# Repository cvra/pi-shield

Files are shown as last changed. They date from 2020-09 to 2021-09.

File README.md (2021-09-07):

# CVRA CAN Raspberry Pi Shield

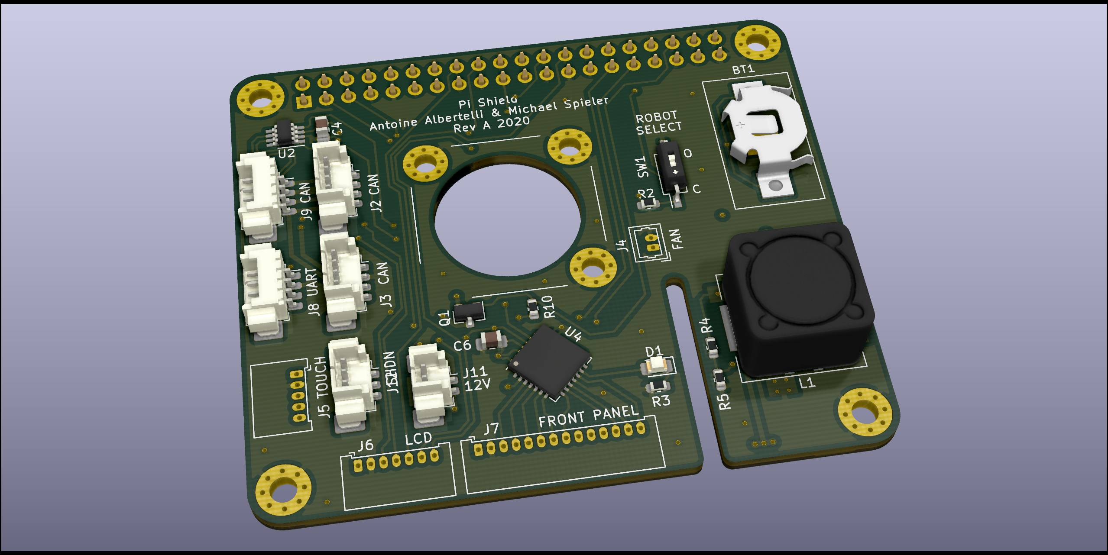
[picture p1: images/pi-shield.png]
3D view of the shield


## Features

* Power supply from 12V to 36V to 5V, 3A.
    Powers the Raspberry Pi, and optionally the CAN bus.
* MCP2515 CAN interface (compatible with Linux/SocketCAN) with transceiver and two connectors for daisy chaining.
* Connector for robot's front panel LEDs (dimmable) and pushbuttons.
* Touchscreen connector (I2C for touch, SPI for pixel data)
* DIP switch to discriminate between robots.
* Battery-backed Realtime Clock allows the robot to keep the time even when powered off.
* UART console
* Power control pins, used to cleanly shutdown the Raspberry Pi before shutting power down.
* Socket for a 20 mm DC fan.
* Slot to allow the use of the PiCam camera module.

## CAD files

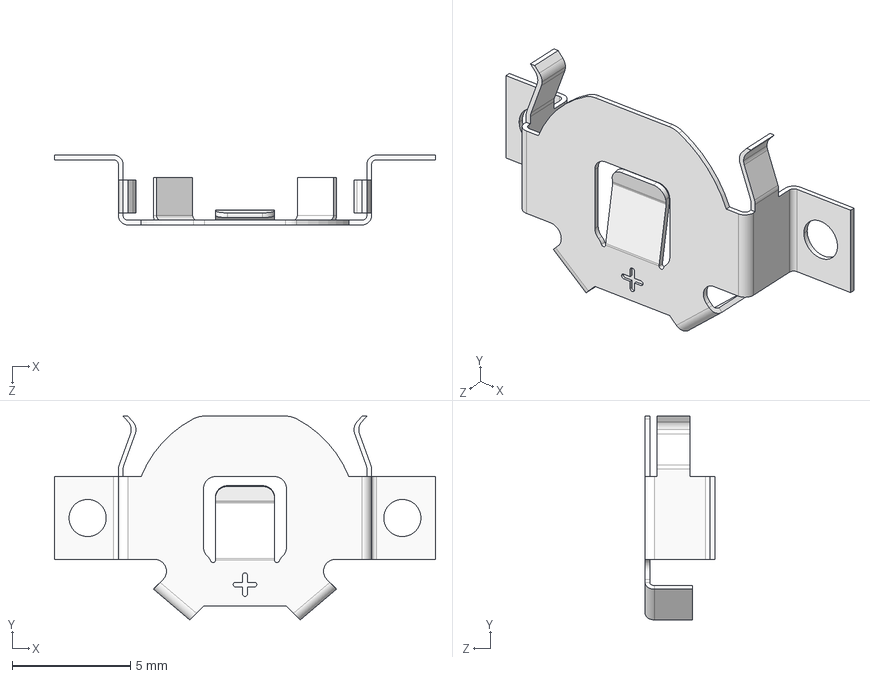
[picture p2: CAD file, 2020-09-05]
3d/BatteryHolder-3030.step
16.1 x 8.61 x 2.95 mm

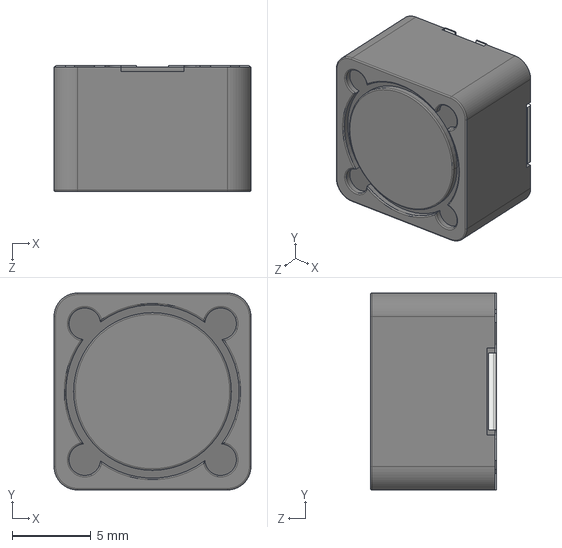
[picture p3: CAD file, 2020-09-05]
3d/DR127.step
12.5 x 12.5 x 8.00 mm

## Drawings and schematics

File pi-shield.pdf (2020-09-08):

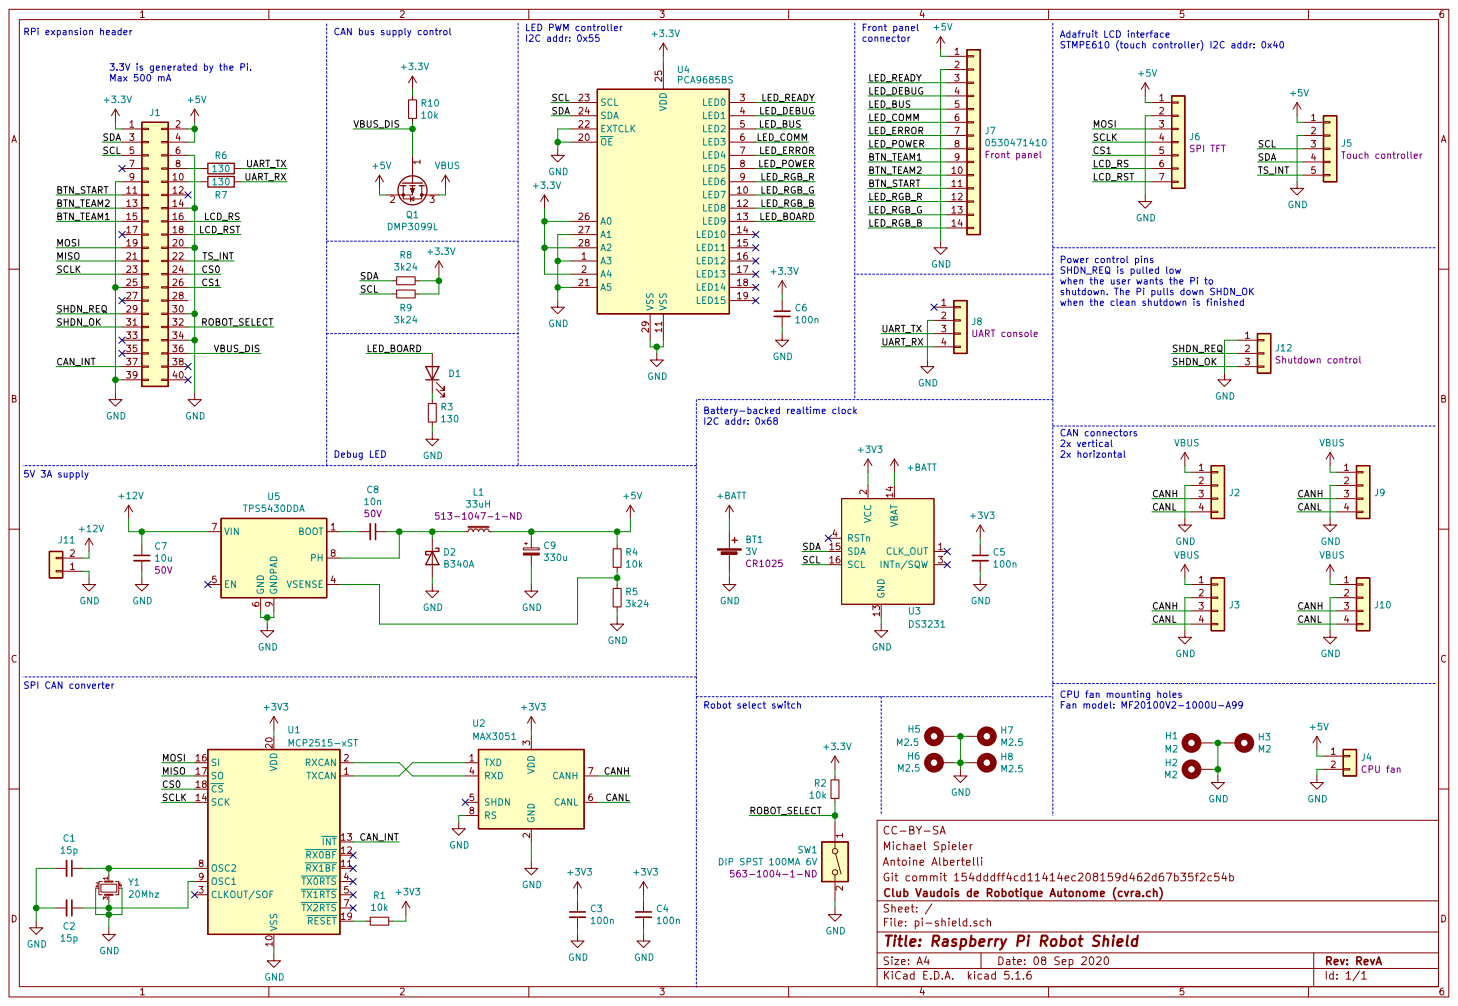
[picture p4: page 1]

Front panel connector LED PWM controller
I2C addr: 0x55

Adafruit LCD interface STMPE610 (touch controller) I2C addr: 0x40

shutdown. The Pi pulls down SHDN_OK when the clean shutdown is finished Battery-backed realtime clock

SHDN_REQ is pulled low
when the user wants the Pi to

3 RXD 4 SHDN 5 CANL 6 CANH 7 RS 8U2MAX3051

File: pi-shield.sch Sheet: / Club Vaudois de Robotique Autonome (cvra.ch) Git commit 154dddff4cd11414ec208159d462d67b35f2c54b Antoine Albertelli Michael Spieler CC-BY-SA

Id: 1/1 Title: Raspberry Pi Robot Shield

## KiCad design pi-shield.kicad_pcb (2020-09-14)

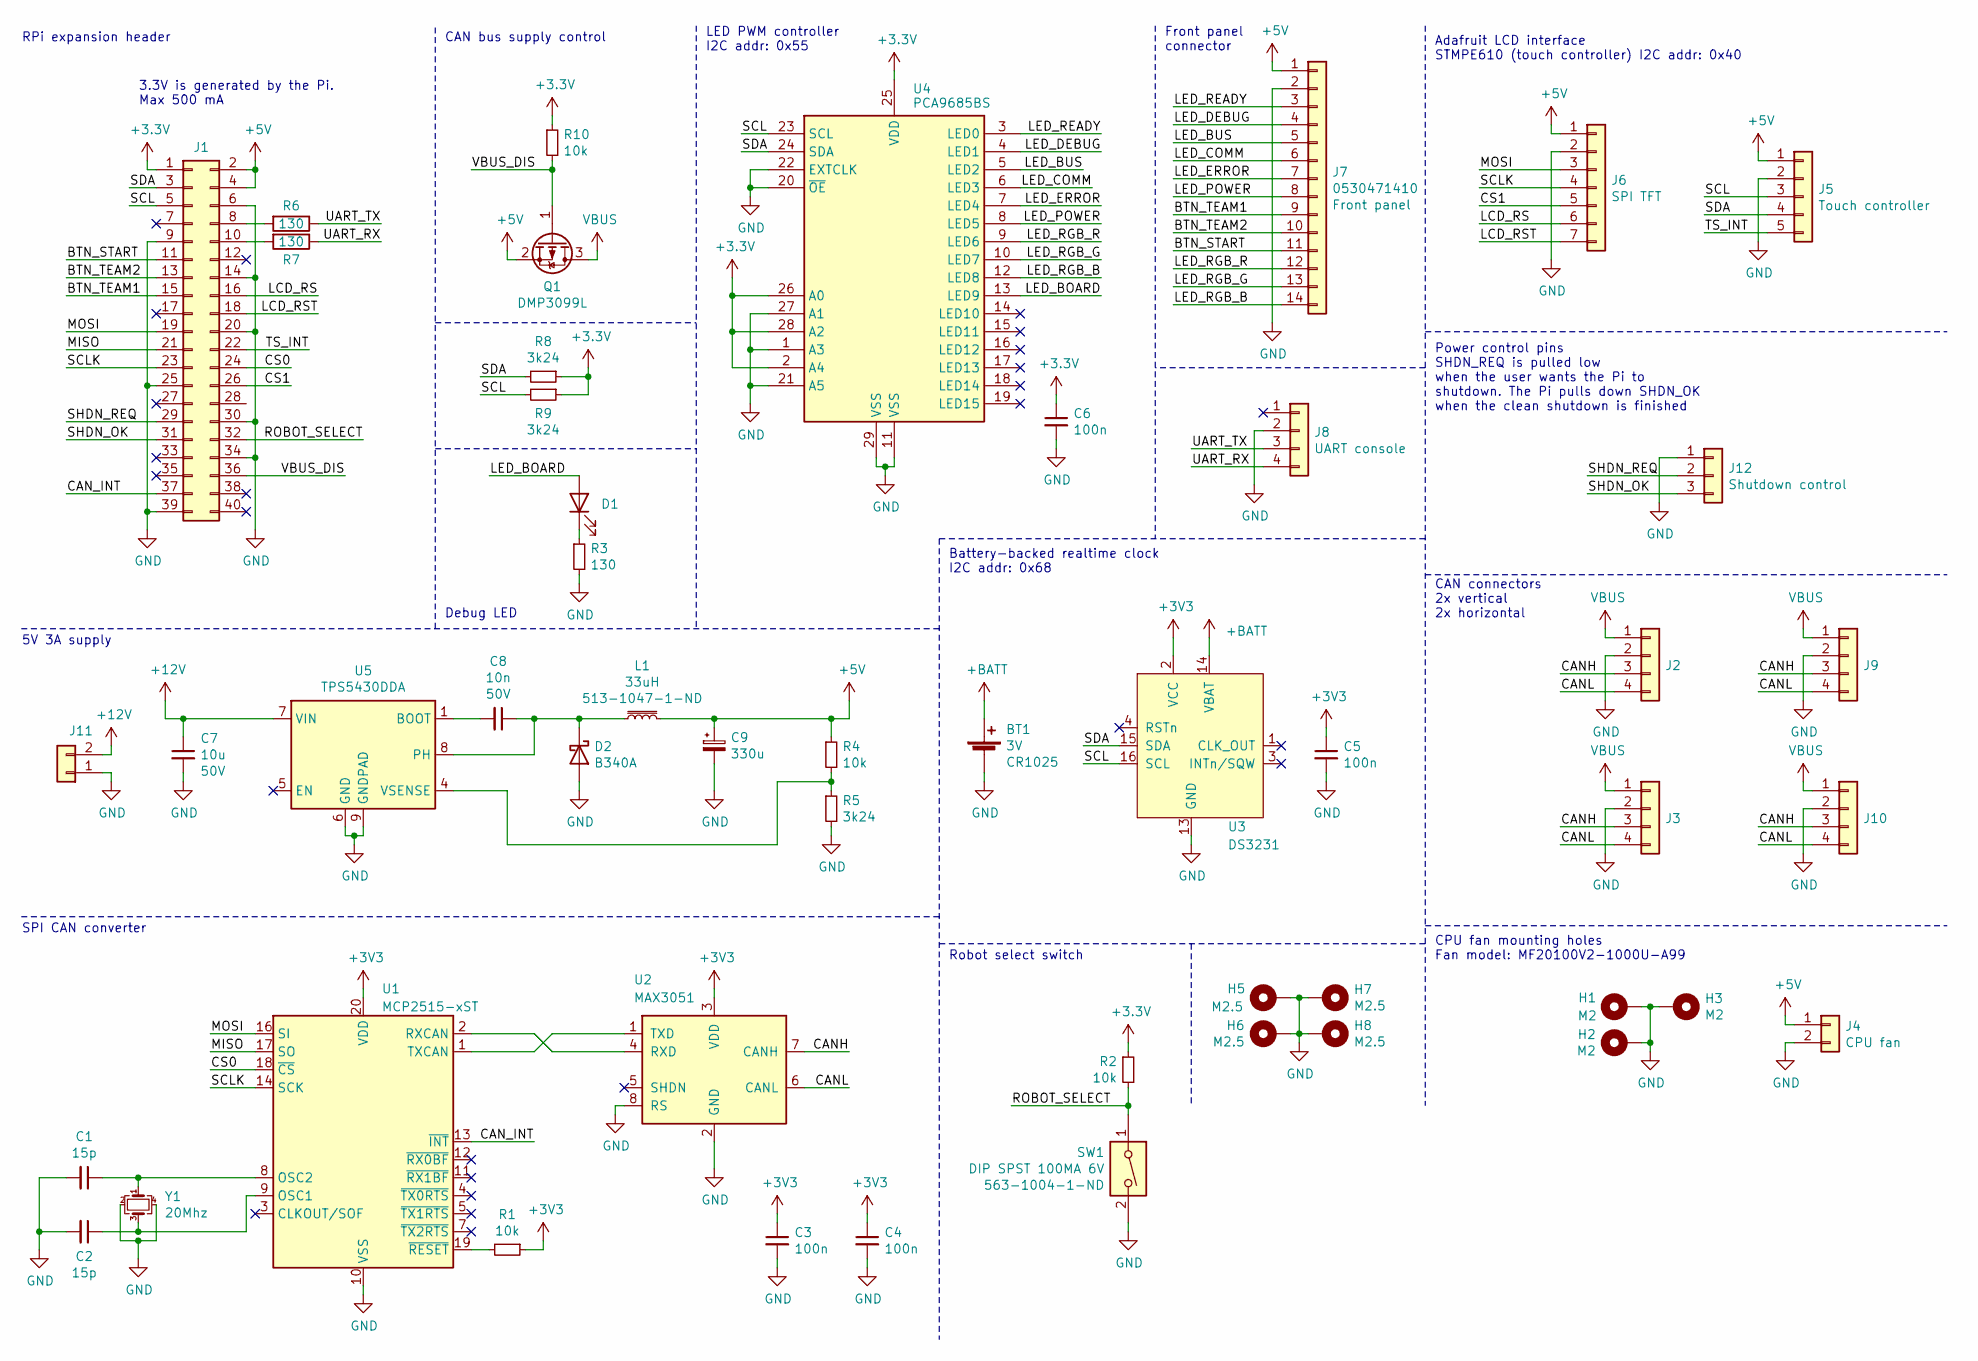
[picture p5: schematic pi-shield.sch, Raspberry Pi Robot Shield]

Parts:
BT1: 3V; 3030; digikey# 36-3030-ND
C1: 15p; C_0805_2012Metric_Pad1.15x1.40mm_HandSolder; digikey# 399-17621-1-ND
C2: 15p; C_0805_2012Metric_Pad1.15x1.40mm_HandSolder
C3: 100n; C_0805_2012Metric_Pad1.15x1.40mm_HandSolder; digikey# 399-1169-1-ND
C4, C5, C6: 100n; C_0805_2012Metric_Pad1.15x1.40mm_HandSolder
C7: 10u; C_2220_5650Metric_Pad1.97x5.40mm_HandSolder; voltage 50V; digikey# 445-3492-1-ND
C8: 10n; C_0603_1608Metric_Pad1.05x0.95mm_HandSolder; voltage 50V; digikey# 399-7842-1-ND
C9: 330u; CP_EIA-7343-30_AVX-N_Pad2.25x2.55mm_HandSolder; voltage 6.3V; digikey# 478-4114-1-ND
D1: SML-LXT0805IW-TR; LED_0805_2012Metric_Pad1.15x1.40mm_HandSolder; digikey# 67-1552-1-ND
D2: B340A; D_SMA; digikey# B340A-E3/61TGICT-ND
H1, H2, H3: M2; MountingHole_2.5mm_Pad_Via
H5, H6, H7, H8: M2.5; MountingHole_2.7mm_M2.5_Pad_Via
J1: Conn_02x20_Odd_Even; PinSocket_2x20_P2.54mm_Vertical; digikey# 1568-1462-ND
J2: Conn_01x04; Molex_PicoBlade_53398-0471_1x04-1MP_P1.25mm_Vertical; digikey# WM7608CT-ND
J3: Conn_01x04; Molex_PicoBlade_53398-0471_1x04-1MP_P1.25mm_Vertical
J4: 0530470210; Molex_PicoBlade_53047-0210_1x02_P1.25mm_Vertical; digikey# WM1731-ND
J5: Conn_01x05; Molex_PicoBlade_53048-0510_1x05_P1.25mm_Horizontal; digikey# WM1745-ND
J6: Conn_01x07; Molex_PicoBlade_53048-0710_1x07_P1.25mm_Horizontal; digikey# WM1747-ND
J7: 0530471410; Molex_PicoBlade_53048-1410_1x14_P1.25mm_Horizontal; digikey# WM17004-ND
J8: Conn_01x04; Molex_PicoBlade_53261-0471_1x04-1MP_P1.25mm_Horizontal; digikey# WM7622CT-ND
J9, J10: Conn_01x04; Molex_PicoBlade_53261-0471_1x04-1MP_P1.25mm_Horizontal
J11: 0530470210; Molex_PicoBlade_53398-0271_1x02-1MP_P1.25mm_Vertical; digikey# WM7606CT-ND
J12: Conn_01x03; Molex_PicoBlade_53398-0371_1x03-1MP_P1.25mm_Vertical; digikey# WM7607CT-ND
L1: 33uH; DR127; digikey# 513-1047-1-ND
Q1: DMP3099L; SOT-23; digikey# DMP3099L-13DICT-ND
R1, R2, R4: 10k; R_0603_1608Metric
R3: 130; R_0603_1608Metric; digikey# 311-130GRCT-ND
R5: 3k24; R_0603_1608Metric; digikey# 311-3.24KHRCT-ND
R6, R7: 130; R_0603_1608Metric
R8, R9: 3k24; R_0603_1608Metric
R10: 10k; R_0603_1608Metric; digikey# 311-10.0KHRCT-ND
SW1: DIP SPST 100MA 6V; SW_DIP_SPSTx01_Slide_Copal_CHS-01B_W7.62mm_P1.27mm; digikey# 563-1004-1-ND
U1: MCP2515-xST; TSSOP-20_4.4x6.5mm_P0.65mm; digikey# MCP2515T-I/STCT-ND
U2: MAX3051; SOT-23-8_Handsoldering; digikey# MAX3051EKA+TCT-ND
U3: DS3231; SOIC-16W_7.5x12.8mm_P1.27mm; digikey# DS3231M+TRLCT-ND
U4: PCA9685BS; QFN-28-1EP_6x6mm_P0.65mm_EP4.25x4.25mm; digikey# 568-5305-1-ND
U5: TPS5430DDA; TI_SO-PowerPAD-8_ThermalVias; digikey# 296-35990-1-ND
Y1: 20Mhz; Crystal_SMD_Abracon_ABM3C-4Pin_5.0x3.2mm; digikey# 535-11292-1-ND

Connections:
+5V: C9.1, J1.2, J1.4, J4.1, J5.1, J6.1, J7.1, L1.2, Q1.2 (S), R4.1
+12V: C7.1, J11.2, U5.7 (VIN)
+BATT: BT1.1 (+), U3.14 (VBAT)
/BTN_START: J1.11, J7.11
/BTN_TEAM1: J1.15, J7.9
/BTN_TEAM2: J1.13, J7.10
/CANH: J2.3, J3.3, J9.3, J10.3, U2.7 (CANH)
/CANL: J2.4, J3.4, J9.4, J10.4, U2.6 (CANL)
/CAN_INT: J1.37, U1.13 (~INT)
/CS0: J1.24, U1.18 (~CS)
/CS1: J1.26, J6.5
/LCD_RS: J1.16, J6.6
/LCD_RST: J1.18, J6.7
/LED_BOARD: D1.2 (A), U4.13 (LED9)
/LED_BUS: J7.5, U4.5 (LED2)
/LED_COMM: J7.6, U4.6 (LED3)
/LED_DEBUG: J7.4, U4.4 (LED1)
/LED_ERROR: J7.7, U4.7 (LED4)
/LED_POWER: J7.8, U4.8 (LED5)
/LED_READY: J7.3, U4.3 (LED0)
/LED_RGB_B: J7.14, U4.12 (LED8)
/LED_RGB_G: J7.13, U4.10 (LED7)
/LED_RGB_R: J7.12, U4.9 (LED6)
/MISO: J1.21, U1.17 (SO)
/MOSI: J1.19, J6.3, U1.16 (SI)
/ROBOT_SELECT: J1.32, R2.2, SW1.1
/SCL: J1.5, J5.3, R9.2, U3.16 (SCL), U4.23 (SCL)
/SCLK: J1.23, J6.4, U1.14 (SCK)
/SDA: J1.3, J5.4, R8.2, U3.15 (SDA), U4.24 (SDA)
/SHDN_OK: J1.31, J12.3
/SHDN_REQ: J1.29, J12.2
/TS_INT: J1.22, J5.5
/UART_RX: J8.4, R7.1
/UART_TX: J8.3, R6.1
/VBUS_DIS: J1.36, Q1.1 (G), R10.2
GND: BT1.2 (-), C1.2, C2.2, C3.2, C4.2, C5.2, C6.2, C7.2, C9.2, D2.2 (A), H1.1, H2.1, H3.1, H5.1, H6.1, H7.1, H8.1, J1.6, J1.9, J1.14, J1.20, J1.25, J1.30, J1.34, J1.39, J2.2, J3.2, J4.2, J5.2, J6.2, J7.2, J8.2, J9.2, J10.2, J11.1, J12.1, R3.2, R5.2, SW1.2, U1.10 (VSS), U2.2 (GND), U2.8 (RS), U3.13 (GND), U4.1 (A3), U4.11 (VSS), U4.20 (~OE), U4.21 (A5), U4.22 (EXTCLK), U4.27 (A1), U4.29 (VSS), U5.6 (GND), U5.9 (GNDPAD), Y1.2, Y1.4
unnamed: C1.1, U1.8 (OSC2), Y1.1
unnamed: C2.1, U1.9 (OSC1), Y1.3
unnamed: C8.1, D2.1 (K), L1.1, U5.8 (PH)
unnamed: C8.2, U5.1 (BOOT)
unnamed: D1.1 (K), R3.1
unnamed: J1.8, R6.2
unnamed: J1.10, R7.2
unnamed: R1.2, U1.19 (~RESET)
unnamed: R4.2, R5.1, U5.4 (VSENSE)
unnamed: U1.1 (TXCAN), U2.1 (TXD)
unnamed: U1.2 (RXCAN), U2.4 (RXD)
VBUS: J2.1, J3.1, J9.1, J10.1, Q1.3 (D)

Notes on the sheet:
CPU fan mounting holes Fan model: MF20100V2-1000U-A99
3.3V is generated by the Pi. Max 500 mA
Power control pins SHDN_REQ is pulled low when the user wants the Pi to shutdown. The Pi pulls down SHDN_OK when the clean shutdown is finished
SPI CAN converter
5V 3A supply
RPi expansion header
CAN bus supply control
Debug LED
LED PWM controller I2C addr: 0x55
Robot select switch
Battery-backed realtime clock I2C addr: 0x68
CAN connectors 2x vertical 2x horizontal
Adafruit LCD interface STMPE610 (touch controller) I2C addr: 0x40
Front panel connector

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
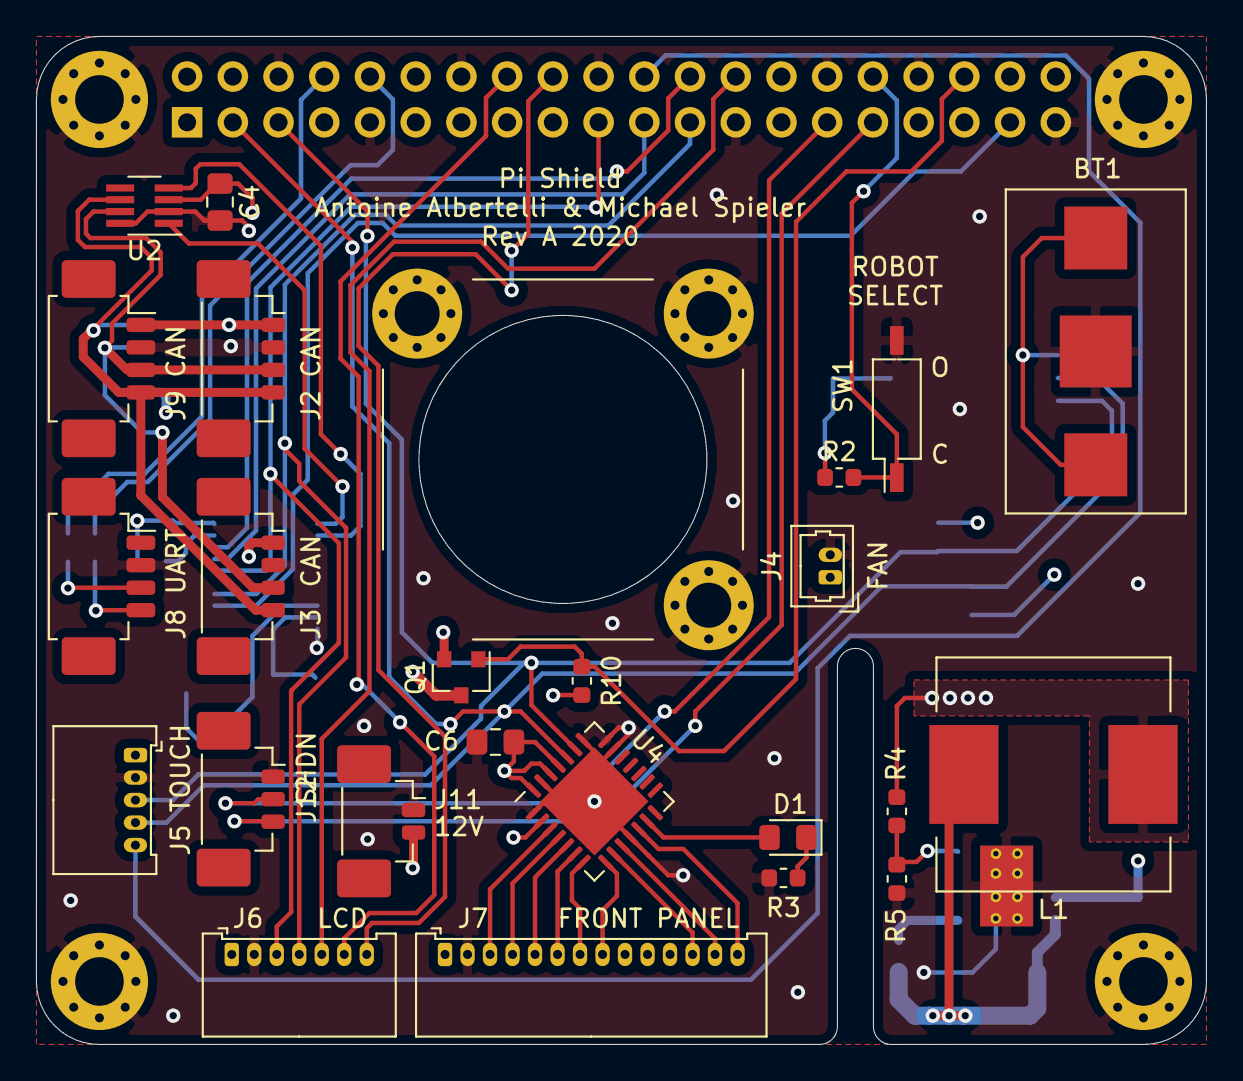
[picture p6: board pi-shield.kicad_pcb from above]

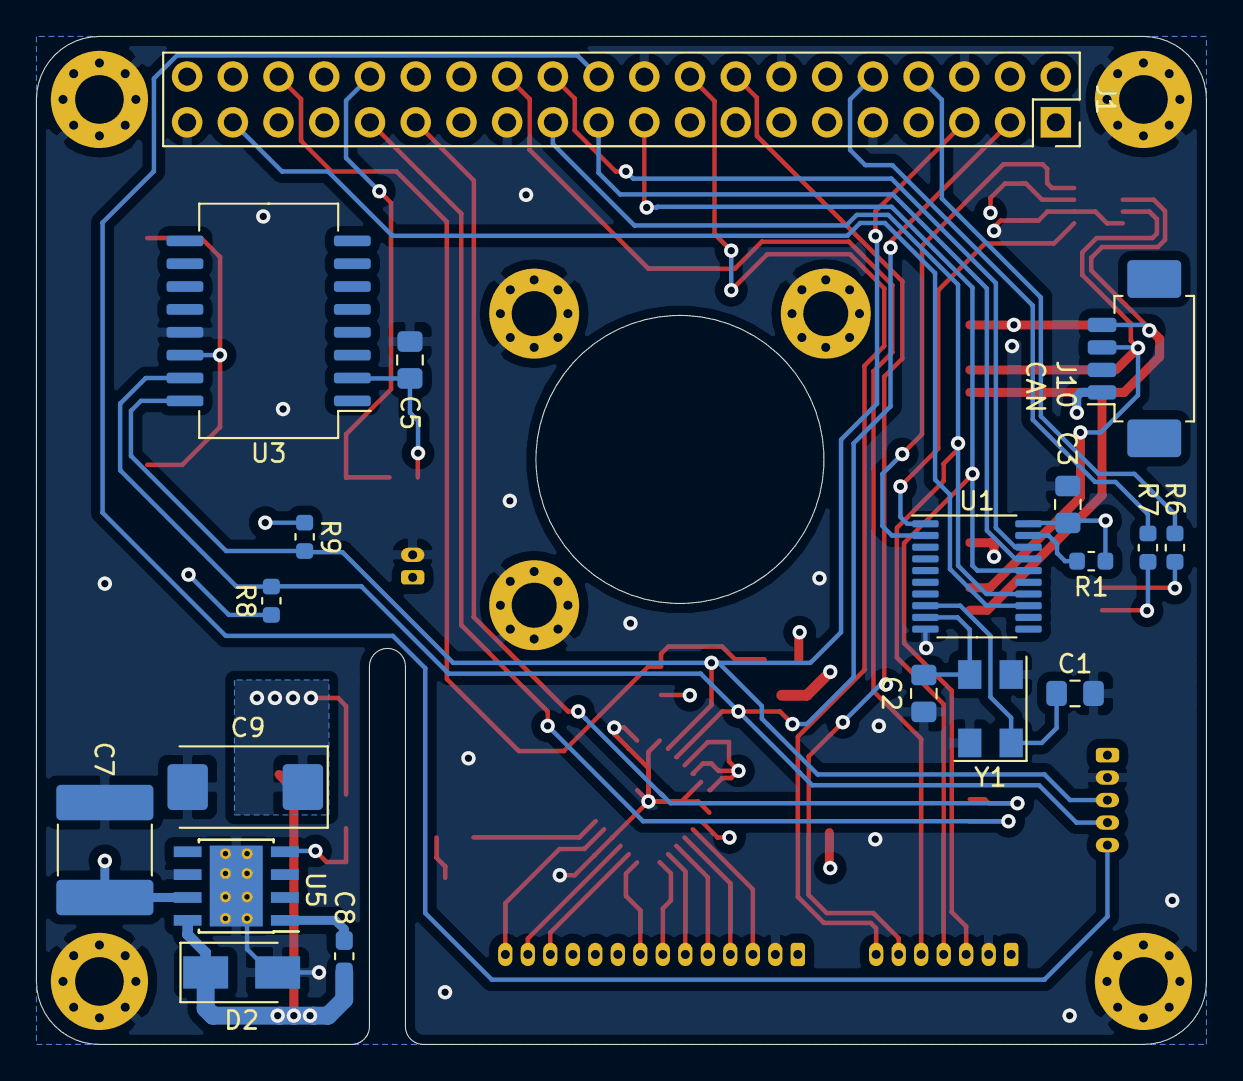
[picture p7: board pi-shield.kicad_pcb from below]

Board: 4 copper layers, 65.0 x 56.0 mm, 50 parts (19 on the bottom side), 49 nets.

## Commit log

2020-06-11 First work session with @nuft
    [pi-shield.kicad_pcb, pi-shield.sch]
2020-06-28 Progressing on pi shield
    [pi-shield.sch]
2020-07-01 Work on some other parts
    [pi-shield.kicad_pcb, pi-shield.sch]
2020-07-22 Progress on schematic and board outline
    [pi-shield.kicad_pcb, pi-shield.sch]
2020-08-26 Initial component placement
    [pi-shield.kicad_pcb, pi-shield.sch]
2020-08-26 Made some progress with layout
    [pi-shield.kicad_pcb, pi-shield.sch]
2020-09-05 First complete layout
    [DR127.step, pi-shield.kicad_pcb, pi-shield.sch]
2020-09-05 Add missing 3d object
    [BatteryHolder-3030.step, pi-shield.kicad_pcb]
2020-09-08 Corrections taking into account @nuft remarks
    [pi-shield.kicad_pcb]
2020-09-08 Prepare for manufacturing adding all digikey#
    [pi-shield.kicad_pcb, pi-shield.sch]
2020-09-08 Integrate git commit in rev field
    [pi-shield.sch]
2020-09-08 Put full commit hash in comments
    [pi-shield.sch]
2020-09-14 Add fabrication files
    [pi-shield-B_Cu.gbl, pi-shield-B_Mask.gbs, pi-shield-B_Paste.gbp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]
2020-09-28 Add a script to generate a BOM in digikey format
